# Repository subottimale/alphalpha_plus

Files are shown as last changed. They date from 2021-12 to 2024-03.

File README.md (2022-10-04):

# Alphalpha+ 30% keyboard
Inspired by the iconic Alpha from PyroL (https://github.com/PyrooL/Alpha), featuring an extra alpha key and spacebar

Alphalpha Plus 3DP blue

Alphalpha Plus stacked

Alphalpha Plus stacked_split

Alphalpha Plus KLE

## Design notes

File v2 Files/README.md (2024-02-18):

This iteration adds bottom row options (KLE link below) and a mondo flex cut above the exploded space bar section
<br />http://www.keyboard-layout-editor.com/#/gists/7b2dbd502e5ef98d23a2ff15da0d303e

If you've gone absolutely mad enough to order this, you'll need: 36 diodes (14N4148 SOD123), pro micro or equivalent, M2 hardware (heatset inserts [tray = 4, shell =8], 4-6mm screws for 3dp case, 4-8 @ 18-20mm screws for stacked case). Optional: o-rings for isolation (2mm OD, 1.5mm ID work well). Oh and you should really get yourself some pro micro sockets and millmax pins, if you can swing 'em

If you use JLC, the dimensions aren't picked up for some reason, so here ya go: (H x W) 86.4mm x 190.5mm

Stacked edge plate, top-mounted shell, and tray case files are available...somewhere...else...in this repo

PLA prints work just fine for these cases; give MJF or SLS a try for a more upscale feel
<br />
<br/>
I highly recommend some amont of isolation mounting for moar fun. Burger for the stacked case, single set of rings between pcb and 3dp tray case, shell case tbd
<br>
<br>
The Colossus case is the latest addition, morphing the edge plate design into a plateless sandwich. So many crumbs everywhere...

AA Plus on the Moon
AA_Plus v2 lights
AA_Plus v2 angle
RGB Tray
AA Plus_moon overhead
AA Plus_moon low angle
AA Plus_moon day LED angle

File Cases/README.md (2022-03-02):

3DP CASE

Base is totally optional, I've run it with just the top and some bumpons.

Also optional are o-rings between pcb and case. I used what was on-hand, but have't done extensive testing to recommend specific products.

STACKED CASE

Left & Right side files are provided for materials where there may be difference in surface finish between top and bottom, i.e. metal. Otherwise, files are identical

Uses M3x20 bolts

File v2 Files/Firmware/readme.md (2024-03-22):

You will need to run this board locally. You won't find it in the configurator
<br />
<br />If you're going the cli route, the default keymap is what I use on a daily basis. It is set up with rgb, mousekeys, combos, and some custom code
<br />
<br />Vial firmware for Alphalpha+ v2 is available, thanks to HaiZeus
<br />
<br />Ready-made hex's are in the Vial folder in this repository: file marked "norgb" disables rgb and enables mouse keys. A RP2040 file is now available, a well.
<br />
<br />If you're using an rgb strip, please note the orientation. Depending on the strip you use, the voltage and ground may be reversed. The header is ordered V D G, but some strips are ordered G D V. Double-check and wire accordingly!
<br />
<br />
<br />rgb header warning

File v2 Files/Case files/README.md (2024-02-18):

**Stacked Case**
<br />You can just cut Fat Stacks, if you won't be using RBG
<br />Thin Stack files are designed to facilitate access to the RGB breakout on the right side of the pcb

Regardless of what kind of stacks you cut, max height on top of pcb is 6mm. Max height on bottom is up to you

Full size setup assembly (o-rings optional but strongly recommended): 
<br />20mm screw
<br />plate
<br />plate
<br />o-ring
<br />pcb
<br />o-ring
<br />plate
<br />plate
<br />plate
<br />nut

Slim assemlby uses 18mm screws and one less plate on the bottom

**3DP Cases**
<br />require heatsets https://www.mcmaster.com/94459a110/ work well
<br>
Note: the Colossus case does not require heatsets, but can use them (recommend to try without first - screws thru case-pcb-case)
<br />Assembly: 
<br /> 1) install heatsets
<br /> 2) screw the pcb to the case. O-rings work with the tray, haven't tested with the shell
<br />
<br />
<br />
Turbo Time

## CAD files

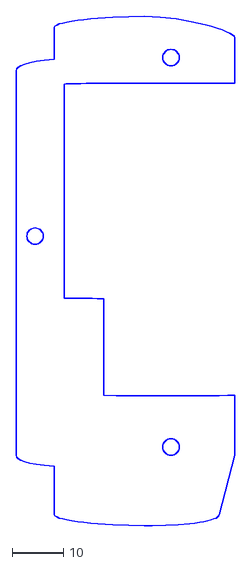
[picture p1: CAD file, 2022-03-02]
Cases/Alphalpha Plus Top Main Left.dxf
42.4 x 99.0

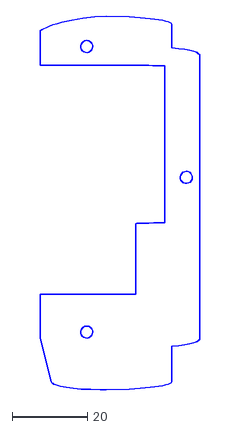
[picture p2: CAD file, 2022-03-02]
Cases/Alphalpha Plus Top Main Right.dxf
42.4 x 99.0

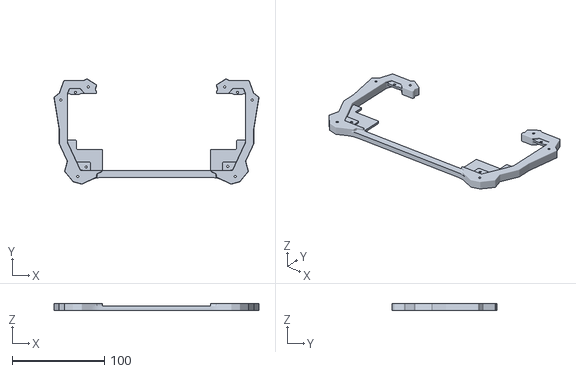
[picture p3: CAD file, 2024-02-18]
v2 Files/Case files/Colossus Bottom.stl
221.8 x 114.0 x 8.00

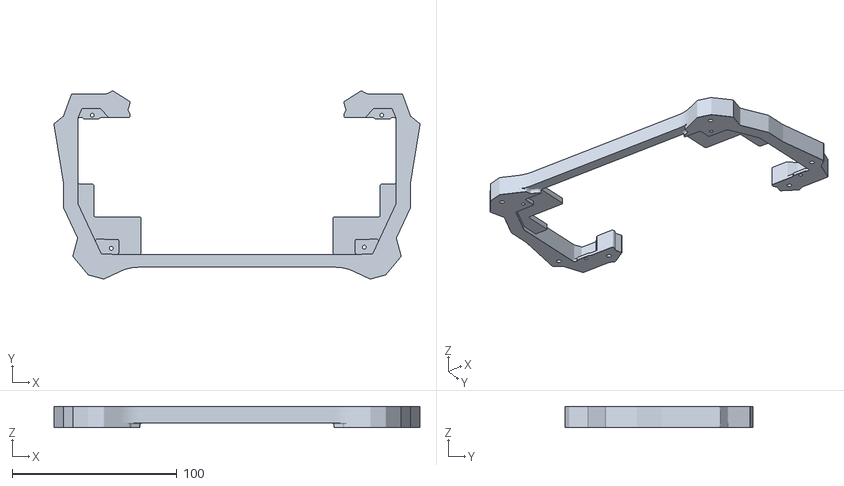
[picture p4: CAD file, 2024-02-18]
v2 Files/Case files/Colossus Top.stl
221.8 x 114.0 x 12.8

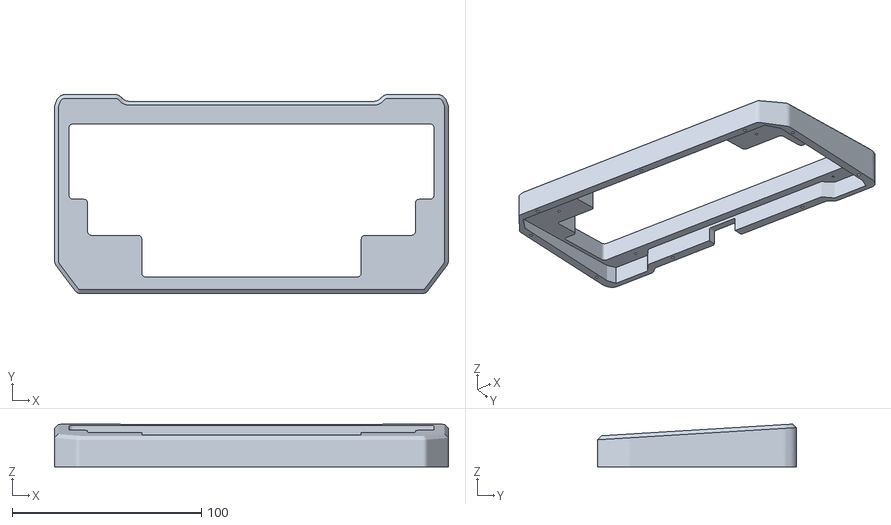
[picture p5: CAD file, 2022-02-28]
Cases/ALPHALPHA PLUS Top vf.stl
208.1 x 105.1 x 22.7

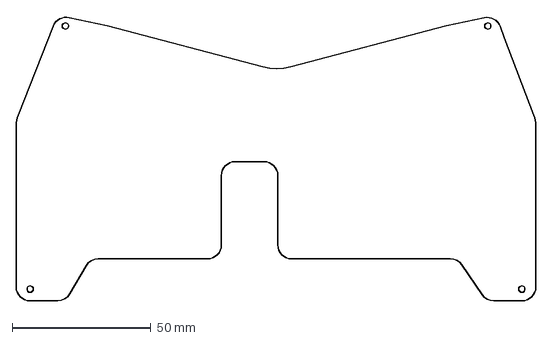
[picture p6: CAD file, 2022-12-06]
v2 Files/Case files/AA Plus v2 Shell Heat_bottom plate.dxf
187.1 x 102.5 mm

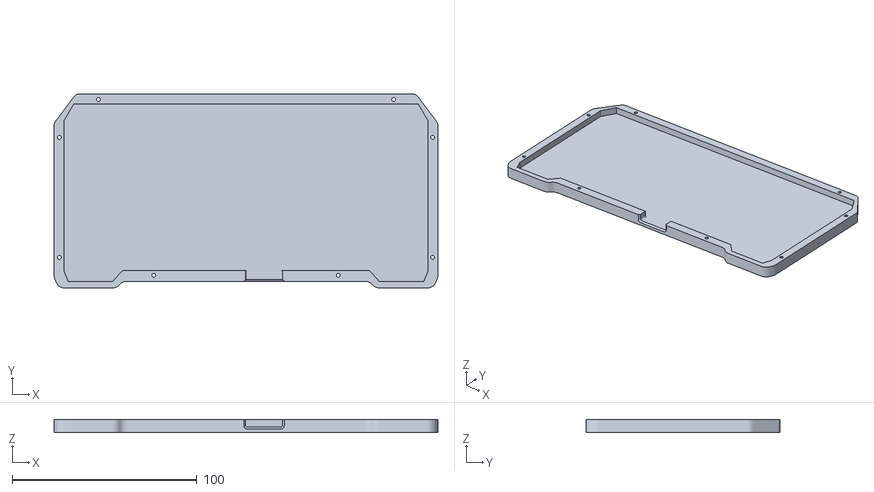
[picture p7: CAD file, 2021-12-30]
Cases/ALPHALPHA PLUS Base.stl
208.1 x 105.1 x 7.00

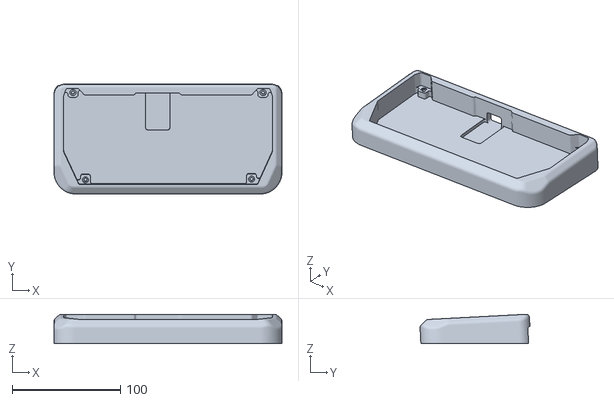
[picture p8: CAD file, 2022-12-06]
v2 Files/Case files/Alphalpha Plus v2 Tray Heat v2.stl
210.5 x 101.5 x 27.2

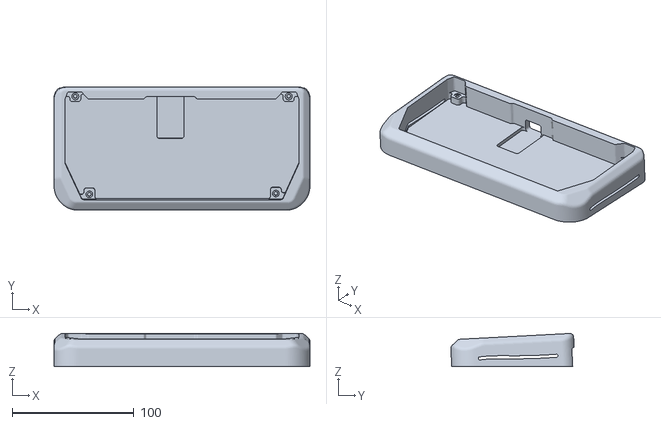
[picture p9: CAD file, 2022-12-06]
v2 Files/Case files/AA_PLUS_v2 Tray_heat_RGB v1.stl
210.5 x 101.5 x 27.2

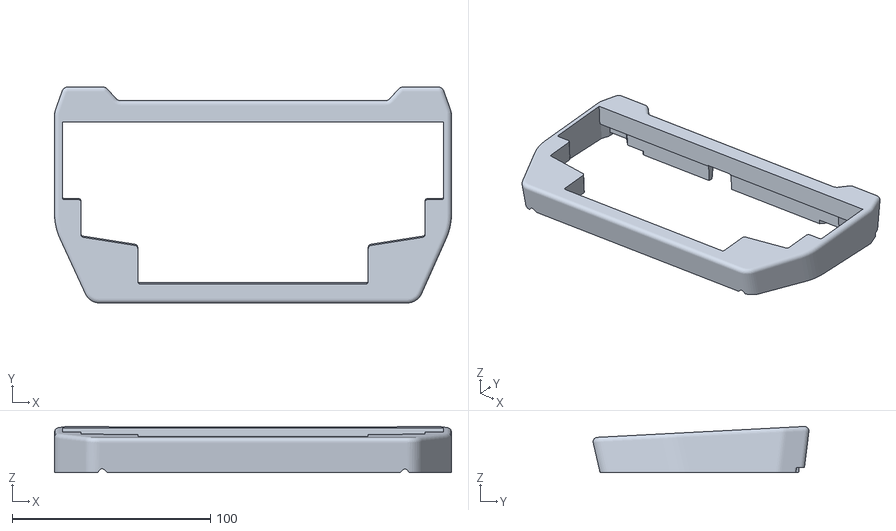
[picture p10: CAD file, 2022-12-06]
v2 Files/Case files/AA_PLUS_v2 Top Shell_Heat.stl
200.5 x 109.0 x 23.3

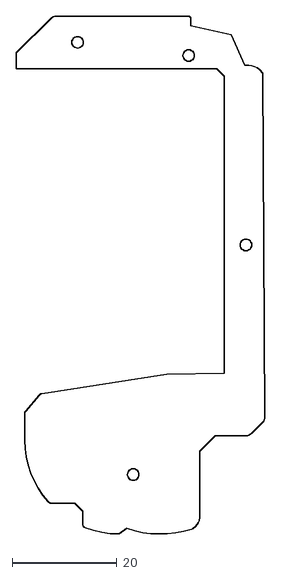
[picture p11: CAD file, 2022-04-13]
v2 Files/Case files/Alphalpha Plus v2_thin stack.dxf
47.5 x 99.2

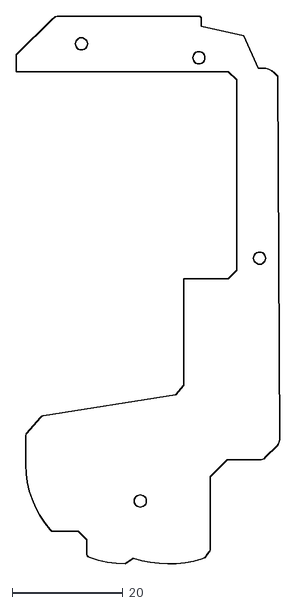
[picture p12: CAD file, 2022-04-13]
v2 Files/Case files/Alphalpha Plus v2_fat stack.dxf
47.5 x 99.2

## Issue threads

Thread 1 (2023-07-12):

Potential issue in wall thickness of v2 top case

arrowtype, 2023-07-12:
Hey, I'm a big fan of this project and the designs in it. I am considering ordering the top shell case from the v2 files, but when JLCpcb checked it, they emailed me with this message:

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

I haven't yet personally checked the measurements in CAD software, but I assume they are accurate in reporting the concern. If I do modify the design, I'd be happy to make a pull request here, but I am currently leaning towards making the sandwich-style case instead. Still, I thought it might be helpful to share this issue here.

Thanks for making and sharing the project!

Closed 2023-07-12.

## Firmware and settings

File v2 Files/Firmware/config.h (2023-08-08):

#pragma once

#include "config_common.h"

/* key matrix size */
#define MATRIX_ROWS 4
#define MATRIX_COLS 10

/* key matrix pins */
#define MATRIX_ROW_PINS { D7, B5, B4, E6 }
#define MATRIX_COL_PINS { D1, D0, D4, C6, B6, B2, B3, B1, F7, F6 }

/* COL2ROW or ROW2COL */
#define DIODE_DIRECTION ROW2COL

/* Set 0 if debouncing isn't needed */
#define DEBOUNCE 5

#define RGB_DI_PIN F4
#ifdef RGB_DI_PIN
#define RGBLIGHT_EFFECT_STATIC_GRADIENT
#define RGBLED_NUM 8
#define RGBLIGHT_HUE_STEP 20
#define RGBLIGHT_SAT_STEP 20
#define RGBLIGHT_VAL_STEP 20
#endif

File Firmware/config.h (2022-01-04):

#pragma once

#include "config_common.h"

/* USB Device descriptor parameter */
#define VENDOR_ID       0x534f
#define PRODUCT_ID      0x612b
#define DEVICE_VER      0x0001
#define MANUFACTURER    OTTIMO
#define PRODUCT         alphalpha plus

/* key matrix size */
#define MATRIX_ROWS 4
#define MATRIX_COLS 10

/* key matrix pins */
#define MATRIX_ROW_PINS { D7, B5, B4, E6 }
#define MATRIX_COL_PINS { D1, D0, D4, C6, B6, B2, B3, B1, F7, F6 }
#define UNUSED_PINS

/* COL2ROW or ROW2COL */
#define DIODE_DIRECTION ROW2COL

/* number of backlight levels */

#ifdef BACKLIGHT_PIN
#define BACKLIGHT_LEVELS 3
#endif

/* Set 0 if debouncing isn't needed */
#define DEBOUNCE 5

/* Mechanical locking support. Use KC_LCAP, KC_LNUM or KC_LSCR instead in keymap */
#define LOCKING_SUPPORT_ENABLE

/* Locking resynchronize hack */
#define LOCKING_RESYNC_ENABLE

#define RGB_DI_PIN F4
#ifdef RGB_DI_PIN
#define RGBLIGHT_ANIMATIONS
#define RGBLED_NUM 5
#define RGBLIGHT_HUE_STEP 8
#define RGBLIGHT_SAT_STEP 8
#define RGBLIGHT_VAL_STEP 8
#endif

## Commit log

2021-12-07 Add files via upload
    gerbers, firmware, case designs
2022-02-28 Add files via upload
    Adjustments to improve keycap coverage and better accommodate base
    [ALPHALPHA PLUS Top vf.stl]
2022-04-13 Add stacked edge case files
    [Alphalpha Plus v2_fat stack.dxf, Alphalpha Plus v2_thin stack.dxf]
2022-04-13 Do I cut Fat Stacks or Thin Stacks?
2022-04-13 add gerbers
    [alphalpha_plus_v2-B_Cu.gbr, alphalpha_plus_v2-B_Mask.gbr, alphalpha_plus_v2-B_Paste.gbr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]
2022-09-14 this is just a shell, it has no bottom
    [Alphalpha Plus v2 Top Shell.stl]
2022-12-06 Remove old shell case
    [Alphalpha Plus v2 Top Shell.stl]
2022-12-06 bottom plate for shell case
    [AA Plus v2 Shell Heat_bottom plate.dxf]
2023-08-08 Update config.h
    modify to comply with current qmk protocols
2024-02-18 add Colossus case
    [Colossus Bottom.stl, Colossus Top.stl]
2024-03-22 givin you a raspberry
